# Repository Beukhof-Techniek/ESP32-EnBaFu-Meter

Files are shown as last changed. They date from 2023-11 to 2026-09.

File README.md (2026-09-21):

# ESP32 Engine, Battery & Fuel Meter

## General

This project shows an example design for an ESP32-based adapter with which a number of Engine, Battery and Fuel related properties can be read, interpreted an communicated with a Signal K host. This design has actually been built and is in use on on my own sailboat.

## Features

- Fuel Level as a ratio (percentage) and volume;

- Alternator Voltage;

- Engine Status (stopped/running);

- Engine Running Time (persistent over Power Cycles);

- Battery Voltage for two Batteries;

- WiFi connection to the Boat Network;

- Calibration possibilities;

- Using the ESP32 platform.

## Fuel Level

The value (resistance) of a Fuel or Water Level Sender is indicative for the (remaining) amount of Liquid in the Tank. In this example, a Wema Fuel Level Sender is used which has the VDO type values: 0 Ohm when empty and 190 Ohm when full. Any other type of Linear Sender will do as long as you calibrate it properly.

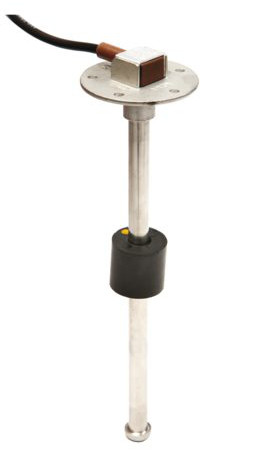
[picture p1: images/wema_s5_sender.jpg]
Wema Fuel and Water Sender


The Sender is connected in series with a 220 Ohm resistor over which the voltage drop is being measured. Due to the inaccuracy of a standard analog input of ESP32 types of processors, an INA219A is being used. A 3.3V zenerdiode keeps a steady voltage over the resistor-sender series connection. The actual value of the Sender determines the voltage drop over the 220 Ohm resistor which in turn is an indication of the Fluid Level in the Tank.

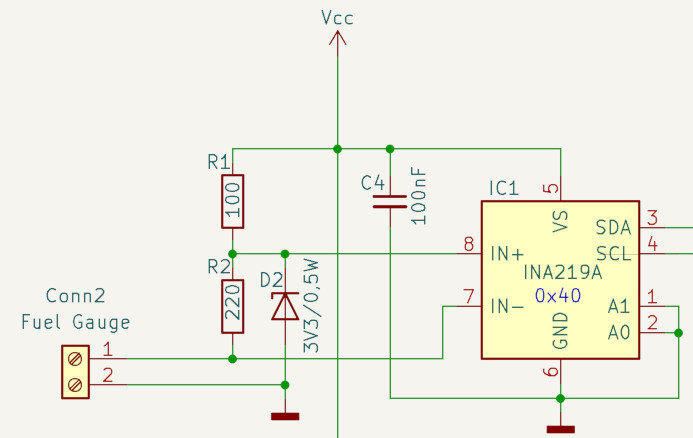
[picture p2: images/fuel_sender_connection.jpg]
Fuel Sender connection


The determined Input Voltage is then calculated into the ratio, a value between 0.0 and 1.0 which can be used to present a percentage (Signal K offers a number of translations), and the volume. The latter is sent to Signal K in m3 but Signal K offers a number of translations for this value as well. Because I found the Wema sender I was using was not linear, there is an additional function with which one can calibrate the resulting values.

The values sent to Signal K are:

- type : the type of Tank;

- capacity : total capacity/volume of the Tank;

- currentLevel : the level of fluid in the Tank as a value 0.0-1.0 (Signal K documentation mentions 0-100% which is incorrect);

- currentVolume : the volume of fluid in the Tank.

## Alternator and Engine values

The Alternator is also connected to an INA219A voltage monitor to obtain an accurate voltage registration. The current sensing capabilities are not being used in this design.

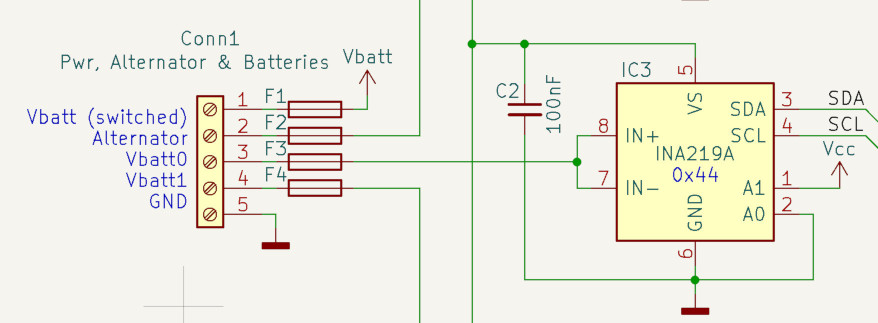
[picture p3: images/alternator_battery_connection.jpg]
Alternator and Battery connection


When the measured voltage is above a certain threshold, the engine is considered as running and time is added to the total runtime and updated in flash memory.

The values sent to Signal K are:

- label : human readable label for the propulsion unit;

- alternatorVoltage : Alternator voltage;

- state : the current state of the Engine;

- runTime : total running time of the Engine (Engine Hours in seconds).

## Battery Voltage

This design provides the possibility to connect and monitor two Batteries. For connection details, see "Alternator and Engine values" above.

The value sent to Signal K is:

- voltage : Voltage measured at or as close as possible to the device.

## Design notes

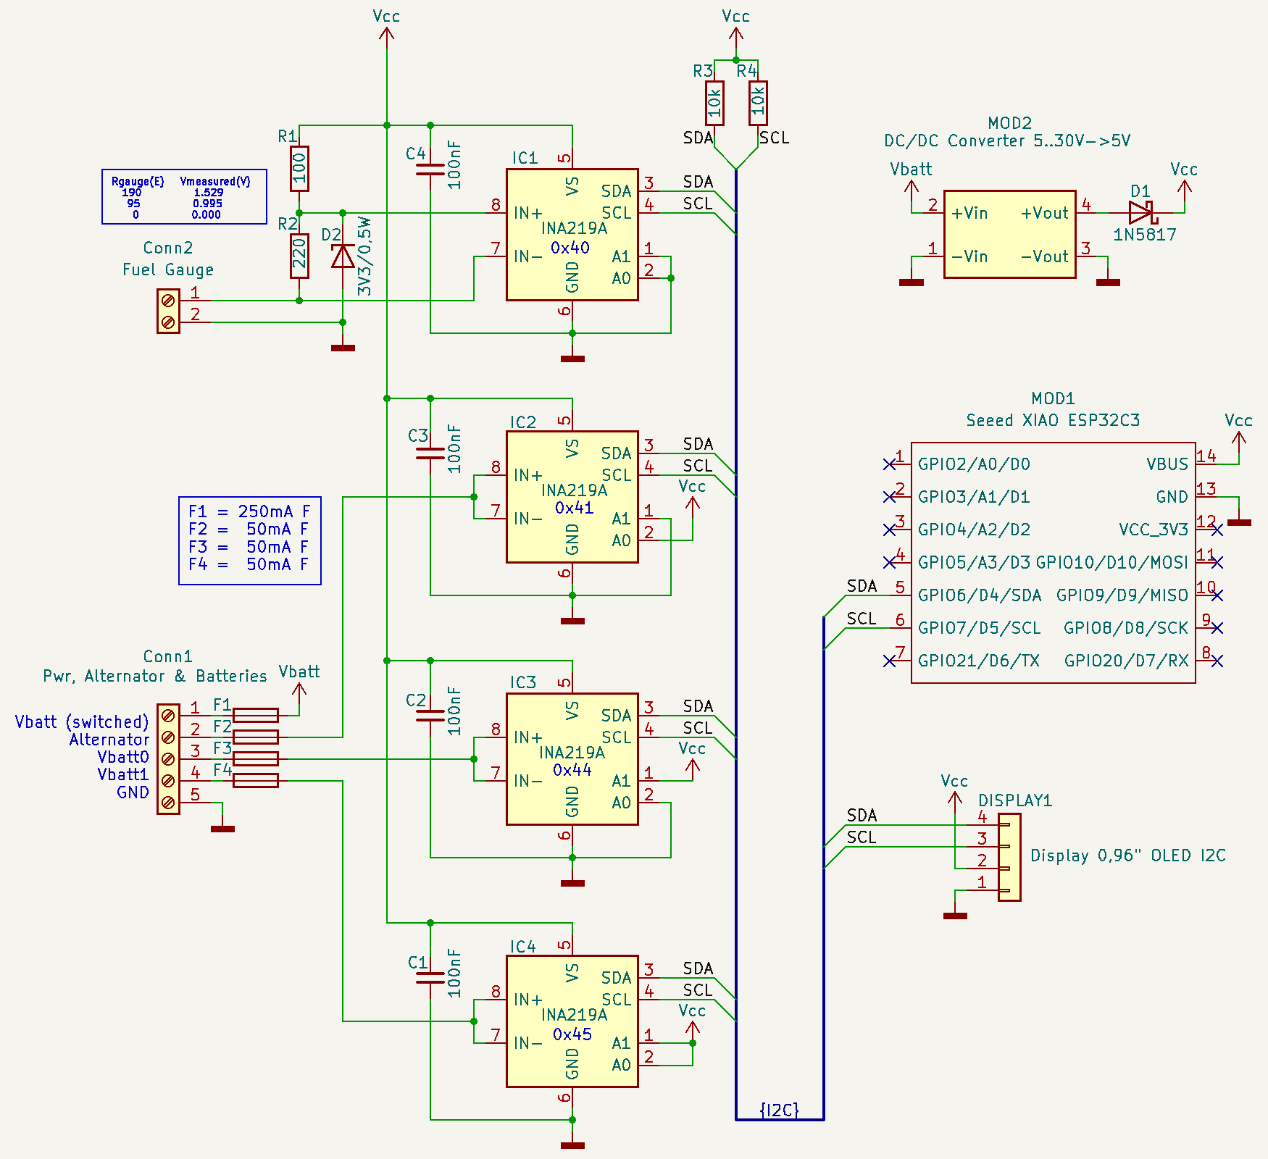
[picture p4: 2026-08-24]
images/enbafu_meter_schematic.png

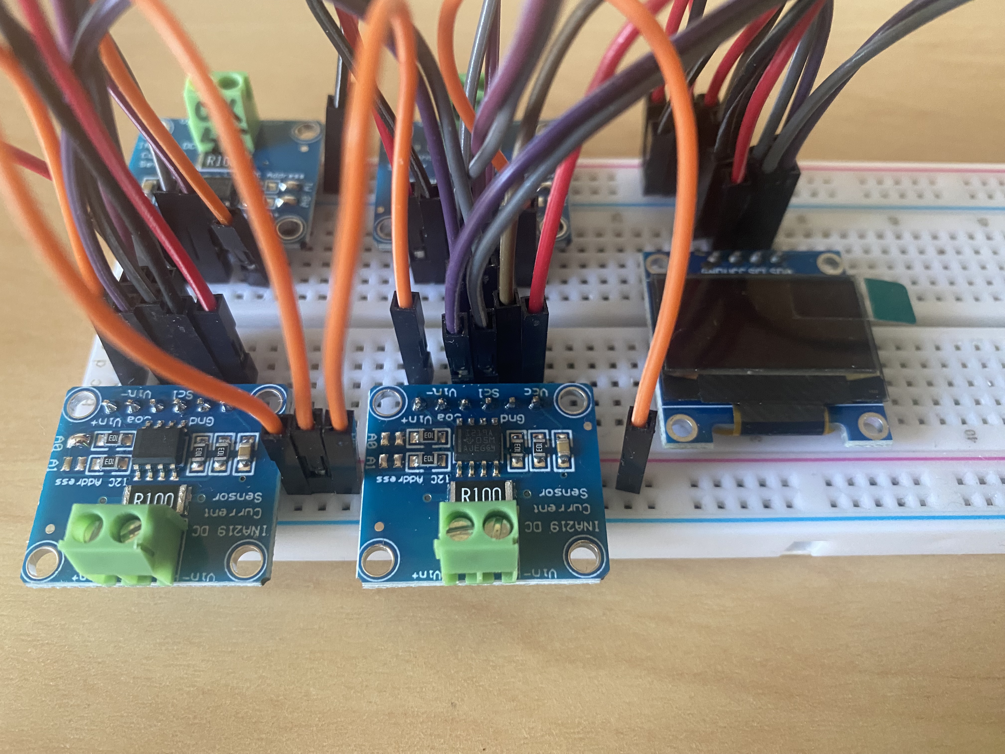
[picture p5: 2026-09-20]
images/breadboard02.jpg

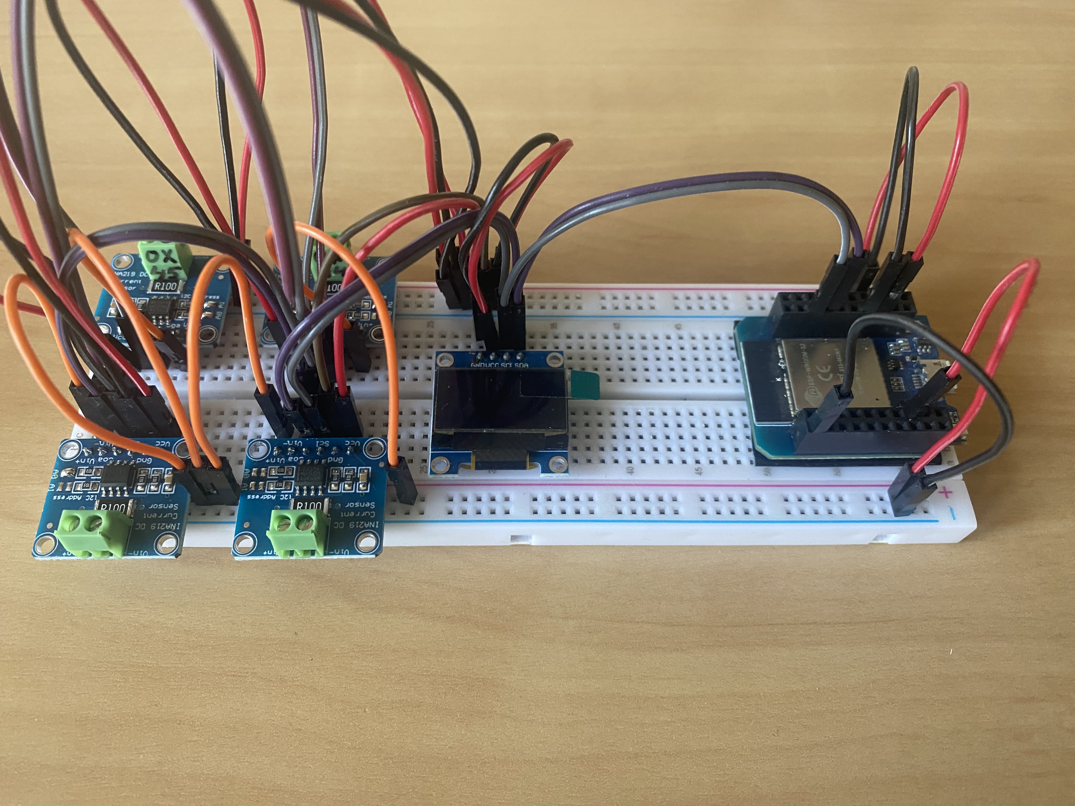
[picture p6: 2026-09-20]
images/breadboard01.jpg

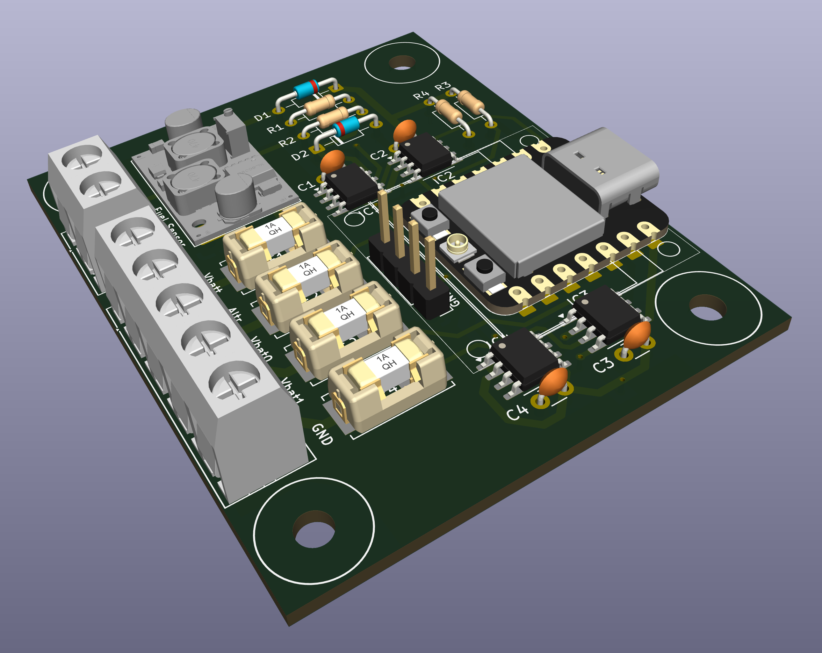
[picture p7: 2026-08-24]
images/enbafu_meter_pcb_3d.png

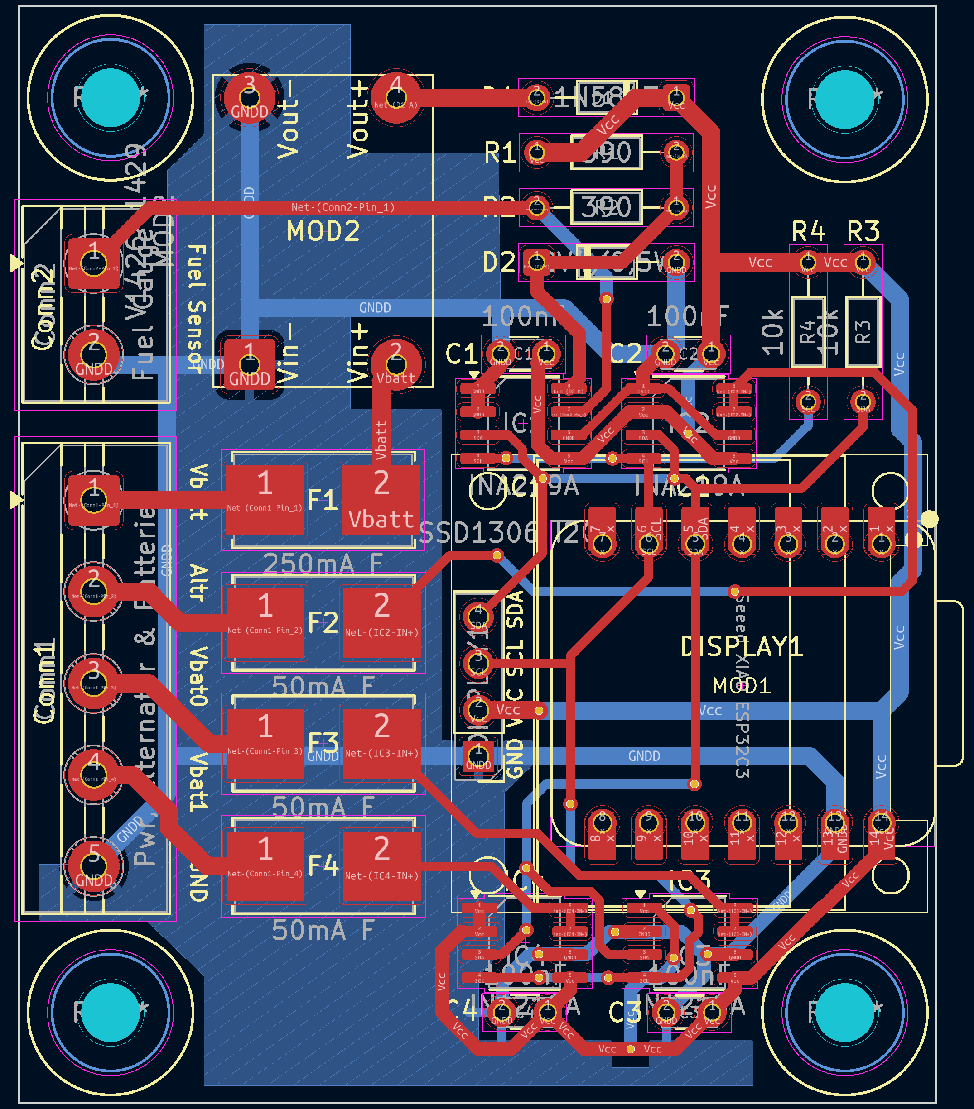
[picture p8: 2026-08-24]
images/enbafu_meter_pcb.png

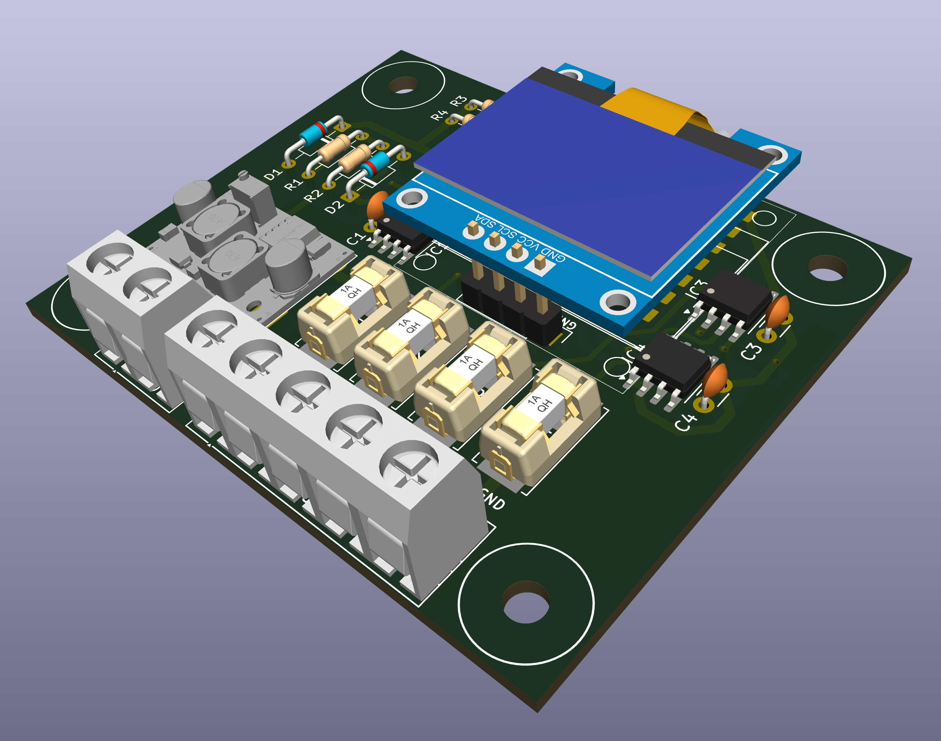
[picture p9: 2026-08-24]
images/enbafu_meter_pcb_3d_oled.png

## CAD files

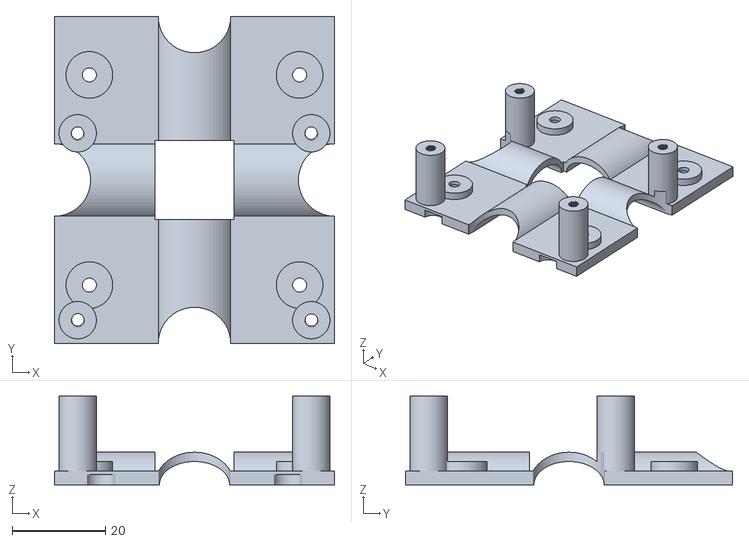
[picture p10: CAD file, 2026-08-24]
documents/EnBaFu Meter Mounting.stl
60.0 x 70.0 x 19.0

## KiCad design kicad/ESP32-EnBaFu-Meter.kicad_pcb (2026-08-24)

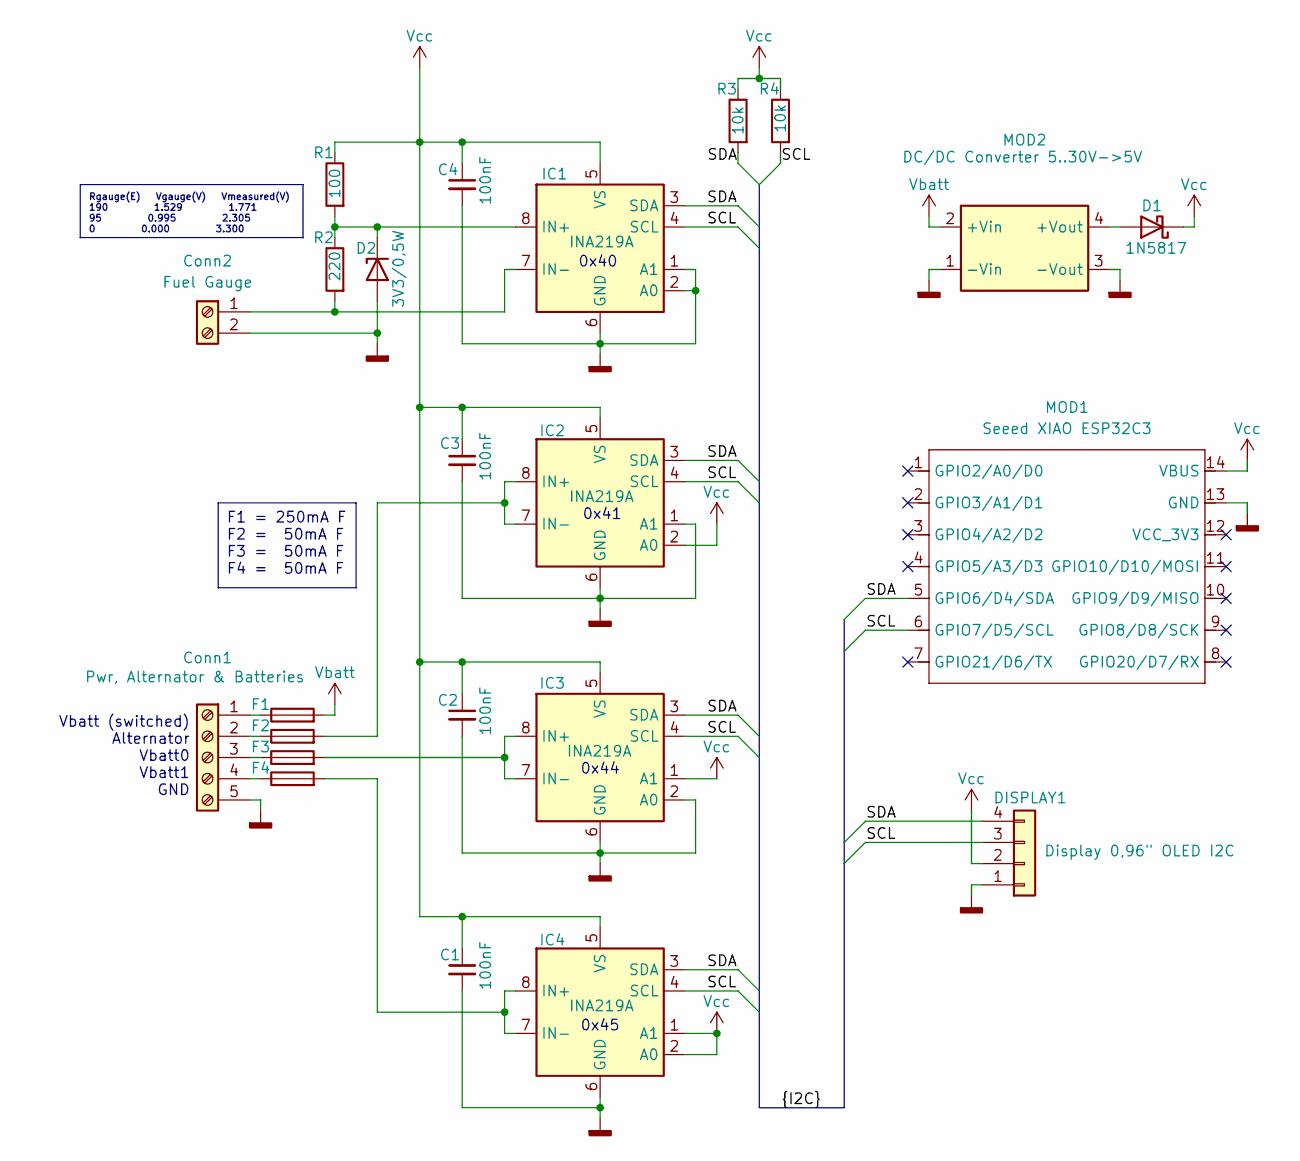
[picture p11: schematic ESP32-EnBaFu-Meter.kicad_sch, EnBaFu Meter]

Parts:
C1, C2, C3, C4: 100nF; C_Disc_D3.0mm_W1.6mm_P2.50mm
Conn1: Pwr, Alternator & Batteries; TerminalBlock_MaiXu_MX126-5.0-05P_1x05_P5.00mm
Conn2: Fuel Gauge; TerminalBlock_MaiXu_MX126-5.0-02P_1x02_P5.00mm
D1: 1N5817; D_DO-34_SOD68_P7.62mm_Horizontal
D2: 3V3/0,5W; D_DO-34_SOD68_P7.62mm_Horizontal
DISPLAY1: Display 0,96" OLED I2C; Display_0.96inch_OLED_IIC
F1: 250mA F; Fuseholder_Littelfuse_Nano2_154x
F2, F3, F4: 50mA F; Fuseholder_Littelfuse_Nano2_154x
IC1, IC2, IC3, IC4: INA219A; SOIC-8_3.9x4.9mm_P1.27mm
MOD1: Seeed XIAO ESP32C3; XIAO-ESP32C3-DIP
MOD2: DC/DC Converter 5..30V->5V; DCDC_Converter_Aliexpress_4pin_17x12mm
R1: 100; R_Axial_DIN0204_L3.6mm_D1.6mm_P7.62mm_Horizontal
R2: 220; R_Axial_DIN0204_L3.6mm_D1.6mm_P7.62mm_Horizontal
R3, R4: 10k; R_Axial_DIN0204_L3.6mm_D1.6mm_P7.62mm_Horizontal

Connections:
/SCL: DISPLAY1.3, IC1.4 (SCL), IC2.4 (SCL), IC3.4 (SCL), IC4.4 (SCL), MOD1.6 (GPIO7/D5/SCL), R4.2
/SDA: DISPLAY1.4, IC1.3 (SDA), IC2.3 (SDA), IC3.3 (SDA), IC4.3 (SDA), MOD1.5 (GPIO6/D4/SDA), R3.2
GNDD: C1.2, C2.2, C3.2, C4.2, Conn1.5, Conn2.2, D2.2 (A), DISPLAY1.1, IC1.1 (A1), IC1.2 (A0), IC1.6 (GND), IC2.1 (A1), IC2.6 (GND), IC3.2 (A0), IC3.6 (GND), IC4.6 (GND), MOD1.13 (GND), MOD2.1 (-Vin), MOD2.3 (-Vout)
unnamed: Conn1.1, F1.1
unnamed: Conn1.2, F2.1
unnamed: Conn1.3, F3.1
unnamed: Conn1.4, F4.1
unnamed: Conn2.1, IC1.7 (IN-), R2.2
unnamed: D1.2 (A), MOD2.4 (+Vout)
unnamed: D2.1 (K), IC1.8 (IN+), R1.2, R2.1
unnamed: F2.2, IC2.7 (IN-), IC2.8 (IN+)
unnamed: F3.2, IC3.7 (IN-), IC3.8 (IN+)
unnamed: F4.2, IC4.7 (IN-), IC4.8 (IN+)
Vbatt: F1.2, MOD2.2 (+Vin)
Vcc: C1.1, C2.1, C3.1, C4.1, D1.1 (K), DISPLAY1.2, IC1.5 (VS), IC2.2 (A0), IC2.5 (VS), IC3.1 (A1), IC3.5 (VS), IC4.1 (A1), IC4.2 (A0), IC4.5 (VS), MOD1.14 (VBUS), R1.1, R3.1, R4.1

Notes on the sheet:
0x44
0x40
0x41
Vbatt (switched) Alternator Vbatt0 Vbatt1 GND
0x45
F1 = 250mA F F2 = 50mA F F3 = 50mA F F4 = 50mA F
Rgauge(E) Vgauge(V) Vmeasured(V) 190 1.529 1.771 95 0.995 2.305 0 0.000 3.300

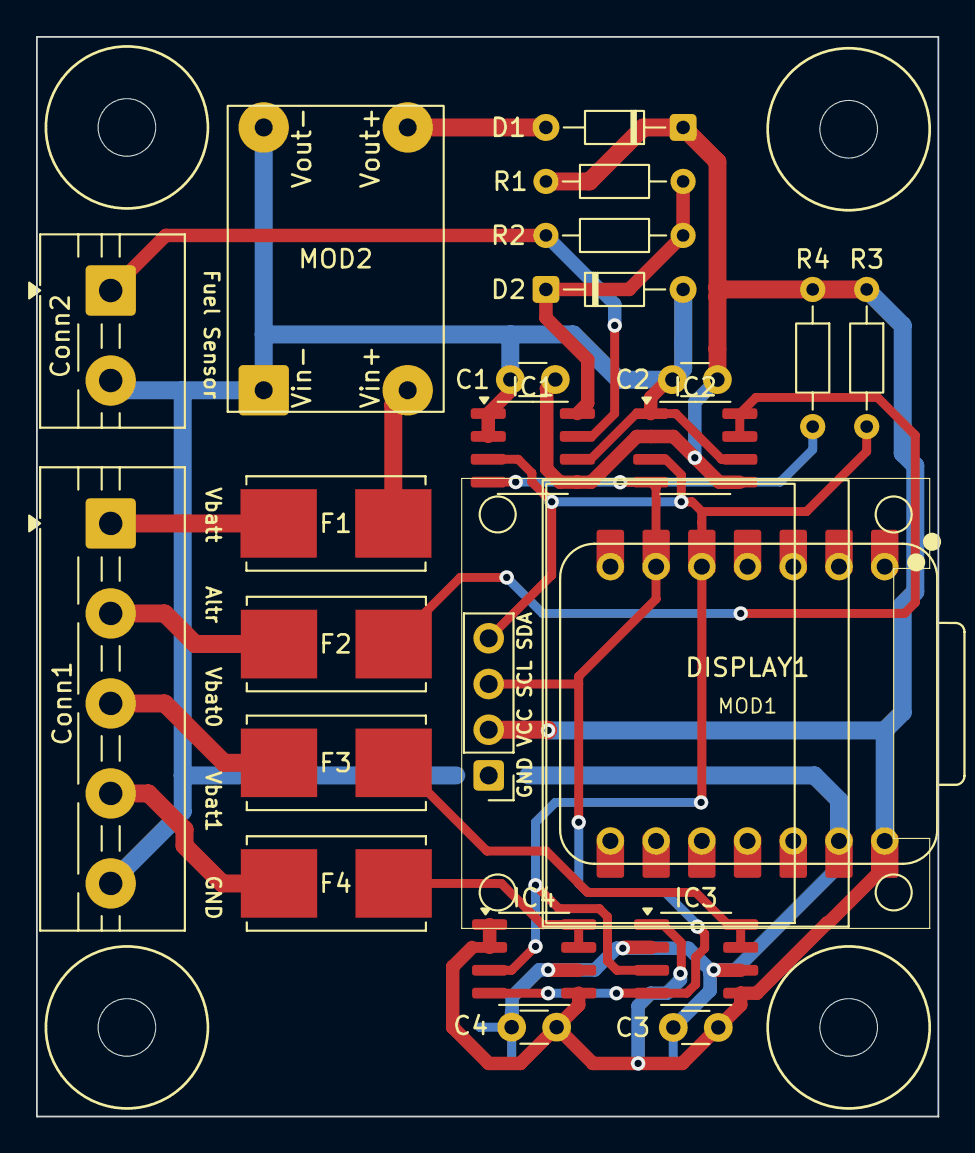
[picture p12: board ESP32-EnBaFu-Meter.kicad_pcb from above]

Board: 2 copper layers, 50.1 x 60.0 mm, 23 parts (0 on the bottom side), 15 nets.

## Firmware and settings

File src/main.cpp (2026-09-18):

// ESP32 Engine, Battery & Fuel Meter for Signal K
//
// This application demonstrates core SensESP concepts in a very
// concise manner. You can build and upload the application as is
// and observe the value changes on the serial port monitor.
//
// You can use this source file as a basis for your own projects.
// Remove the parts that are not relevant to you, and add your own code
// for external hardware libraries.

#include "sensesp_app_builder.h"
#include "sensesp/sensors/analog_input.h"
#include "sensesp/signalk/signalk_output.h"
#include "sensesp/system/lambda_consumer.h"
#include "sensesp/transforms/linear.h"
#include "sensesp/transforms/moving_average.h"
#include <Preferences.h>
#include "includes/EnBaFu_SSD1306.h"
#include <Adafruit_INA219.h>

// *************************************************************************************
// ************************************ PARAMETERS *************************************
// *************************************************************************************

// Replace with your network credentials
const char *wifi_ssid = "your-wifi-devices-ssid";
const char *wifi_password = "your-wifi-devices-password";
const char *hostname = "esp32-enbafu-meter"; // ESP32 Engine, Battery & Fuel Meter (or whatever name you think is valid)

// Replace with your level meter measurements and tank volume
const float tank_voltage_full = 1.660;  // Measured input voltage at full tank (maximum level, use debug info)
const float tank_voltage_empty = 0.000; // Measured input voltage at empty tank (minimum level, use debug info)
const char *tank_type = "diesel";       // Type of tank (diesel, petrol, rum, ...)
const float tank_capacity = 0.060;      // Tank capacity in m3

// Replace with your alternator measurements
// Note: It can be the case that there is a certain voltage on the alternator while the Engine is stopped.
//       This happens for instance when the Alternator is connected to a Victron ArgoFET or similar.
const float alternator_voltage_min = 6.0;      // The minimum voltage from the alternator at which we can safely assume the engine is running (see note above)
unsigned long initial_engine_running_time = 0; // Set this to whatever value you like the runtime counter to start at
                                               // (only needed at the first use or when flash has been cleared). You
                                               // can safely keep it at 0.

// Signal K client config
// Important note: when changing the Signal K server address/connecting to a different Signal K server
// and therefore changing the sk_server_address value below, you need to CLEAR THE FLASH from the ESP
// as well because SensESP stores this value in its config path and prefers that value over whatever
// you feed the builder constructor below. After clearing flash, you might want to re-enter the last known
// engine runTime as the initial_engine_running_time value above to omit the counter starting from 0 again.
const char *sk_server_address = "192.168.20.1";
const uint16_t sk_server_port = 3000;

// *************************************************************************************
// ********************************** END PARAMETERS ***********************************
// *************************************************************************************

#define INA219_FUEL_I2C_ADDRESS (0x40) // Fuel level measurement device
#define INA219_ALTR_I2C_ADDRESS (0x41) // Alternator voltage measurement device
#define INA219_BAT0_I2C_ADDRESS (0x44) // Battery 0 voltage measurement device
#define INA219_BAT1_I2C_ADDRESS (0x45) // Battery 1 voltage measurement device

using namespace sensesp;

Preferences preferences;

// Instantiate the oled display
EnBaFu_SSD1306 oledDisplay(&Wire);

// Instantiate the Vin measurement chips
Adafruit_INA219 ina219_fuel(INA219_FUEL_I2C_ADDRESS); // Fuel level measurement device
Adafruit_INA219 ina219_altr(INA219_ALTR_I2C_ADDRESS); // Alternator voltage measurement device
Adafruit_INA219 ina219_bat0(INA219_BAT0_I2C_ADDRESS); // Battery 0 voltage measurement device
Adafruit_INA219 ina219_bat1(INA219_BAT1_I2C_ADDRESS); // Battery 1 voltage measurement device

String secToHMS(unsigned long seconds){
  if (seconds == 0) {
    return "parameter error";
  } else {
    unsigned long minutes = seconds / 60;
    unsigned long hours = minutes / 60;
    char secondsBuff[3];
    sprintf(secondsBuff, "%02d", seconds%60);
    char minutesBuff[3];
    sprintf(minutesBuff, "%02d", minutes%60);
    return (String)hours + ":" + minutesBuff + ":" + secondsBuff;
  }
}

unsigned long previous_time = 0;
unsigned long engine_running_time = 0;

// Correction function due to non-linearity of the gauge
float gaugeCorrection(float input) {
  // return 1; // For debug purposes such as calibration
  float tank_voltage_relative = (input - tank_voltage_empty) / (tank_voltage_full - tank_voltage_empty);
  if (tank_voltage_relative < 0.131) {
    return 1;
  } else if (tank_voltage_relative < 0.353) {
    return 0.47592;
  } else if (tank_voltage_relative < 0.518) {
    return 0.56386;
  } else if (tank_voltage_relative < 0.63) {
    return 0.63262;
  } else if (tank_voltage_relative < 0.701) {
    return 0.7491;
  } else if (tank_voltage_relative < 0.765) {
    return 0.85041;
  } else if (tank_voltage_relative < 0.851) {
    return 0.94318;
  } else if (tank_voltage_relative < 0.953) {
    return 0.96576;
  } else {
    return 1;
  }
};

/*
 * The setup function performs one-time application initialization.
 */
void setup() {
  SetupLogging();

  /*
   * Set up the OLED display, clears the display and draws the splash screen
   */
  oledDisplay.begin(SSD1306_SWITCHCAPVCC, OLEDDISPLAY_I2C_ADDRESS);
  oledDisplay.clearDisplay(); // Not really necessary because drawSplashScreen() also takes care of this (just in case the splash screen is omitted)
  oledDisplay.setTextSize(1);
  oledDisplay.setTextColor(WHITE);
  oledDisplay.drawSplashScreen();
  delay(2000);  // Give people time to read the splash screen ;)

  /*
   * Set up the INA219 hardware
   */
  ina219_fuel.begin(); // Fuel level measurement device
  ina219_altr.begin(); // Alternator voltage measurement device
  ina219_bat0.begin(); // Battery 0 voltage measurement device
  ina219_bat1.begin(); // Battery 1 voltage measurement device

  /*
   * Construct the global SensESPApp() object
   */
  SensESPAppBuilder builder;
  sensesp_app = builder.set_hostname(hostname)
                      ->set_wifi_client(wifi_ssid, wifi_password)
                      ->set_sk_server(sk_server_address, sk_server_port)
                      ->get_app();

  #ifndef ONLY_SETUP

  // Retrieve the last known engine_running_time value
  if (preferences.begin("propulsion", false)) {
    // When opening the preferences returns a false, the value of engine_running_time will remain 0
    // which will "block" the storage of the parameter further on. Also it will be kept at 0 and shown
    // as such (and the text "parameter error") in the displays so the user will know there is something
    // wrong with the device.
    engine_running_time = preferences.getULong("main_runTime", 1); // Set to default at 1 to get it off the "error" value of 0
  }

  /**
   * Create a series of new Repeat Sensors that obtain data (from the I2C sources) periodically.
   */
  const unsigned int sensor_read_interval = 5000; // Define how often (in milliseconds) new samples are acquired
  auto *tank_voltage = new RepeatSensor<float>(sensor_read_interval, []() { return ina219_fuel.getBusVoltage_V(); });
  auto* alternator_voltage = new RepeatSensor<float>(sensor_read_interval, []() { return ina219_altr.getBusVoltage_V(); });
  auto* battery0_voltage = new RepeatSensor<float>(sensor_read_interval, []() { return ina219_bat0.getBusVoltage_V(); });
  auto* battery1_voltage = new RepeatSensor<float>(sensor_read_interval, []() { return ina219_bat1.getBusVoltage_V(); });
  ESP_LOGD(__FILE__, "tank_voltage, alternator_voltage and batteryx_voltage Instantiated!");

  /**
   * Add observers that print out and display the current value of the obtained data and some calculations every time it changes.
   */
  tank_voltage->attach([tank_voltage]() {
    // Correction of the measured value
    char levelBuffer[5];
    sprintf(levelBuffer, "%d%%", (int)(gaugeCorrection(tank_voltage->get()) * (((tank_voltage->get() - tank_voltage_empty) / (tank_voltage_full - tank_voltage_empty)) * 100)));
    oledDisplay.printAt(35, 42, levelBuffer);
    ESP_LOGI(__FILE__, "\n\nAvailable tank_level values:\ntank_voltage_empty = %f\ntank_voltage_full = %f\nvoltage measured = %f\ncalculated level = %f\n", tank_voltage_empty, tank_voltage_full, tank_voltage->get(), ((tank_voltage->get() - tank_voltage_empty) / (tank_voltage_full - tank_voltage_empty)));
  });
  alternator_voltage->attach([alternator_voltage]() {
    char alternatorBuffer[7];
    sprintf(alternatorBuffer, "%.2fV", alternator_voltage->get());
    oledDisplay.printAt(35, 3, alternatorBuffer);
    oledDisplay.printAt(35, 55, secToHMS(engine_running_time));
    ESP_LOGI(__FILE__, "\n\nAvailable alternator_voltage value:\nvoltage measured = %f\n", alternator_voltage->get());
  });
  battery0_voltage->attach([battery0_voltage]() {
    char battery0Buffer[7];
    sprintf(battery0Buffer, "%.2fV", battery0_voltage->get());
    oledDisplay.printAt(35, 16, battery0Buffer);
    ESP_LOGI(__FILE__, "\n\nAvailable battery0_voltage value:\nvoltage measured = %f\n", battery0_voltage->get());
  });
  battery1_voltage->attach([battery1_voltage]() {
    char battery1Buffer[7];
    sprintf(battery1Buffer, "%.2fV", battery1_voltage->get());
    oledDisplay.printAt(35, 29, battery1Buffer);
    ESP_LOGI(__FILE__, "\n\nAvailable battery1_voltage value:\nvoltage measured = %f\n", battery1_voltage->get());
  });
  ESP_LOGD(__FILE__, "tank_level, alternator_voltage and batteryx_voltage Attached!");

  /**
   * Lambda transformer for registering and storing the Engine Running Time and returning the Engine State
   */
  auto measuredAlternatorVoltageToEngineStateTransformer = new LambdaTransform<float, String>([](float input) -> String {
    unsigned long current_time = millis();
    if (input < alternator_voltage_min) { // Below alternator_voltage_min it is unsure if the engine is running
      previous_time = current_time;
      return "stopped";
    } else if (engine_running_time > 0) {
      if (engine_running_time < initial_engine_running_time) {
        // Set engine_running_time to a certain initial value to start counting from
        engine_running_time = initial_engine_running_time;
      }
      // Calculate runTime in seconds
      engine_running_time += (ulong)(current_time-previous_time)/1000;
      // Store runTime
      preferences.putULong("main_runTime", engine_running_time);
      previous_time = current_time;
      return "running";
    } else { // A value of 0 is an indication that there is something wrong
      previous_time = current_time;
      return "parameter error";
    }
  });

  /**
   * Linear transformers for calibrating output values
   * 
   * gaugeCorrectionTransformer corrects the non-linearity of the fuel gauge (using the gaugeCorrection function)
   * linearTankLevelTransformer takes the tank voltage at minimum level (empty) and maximum level (full) in consideration to create a decent %
   * linearTankVolumeTransformer alse takes the tank capacity into consideration to create a decent volume (m3)
   */
  auto gaugeCorrectionTransformer = new LambdaTransform<float, float>([](float input) -> float {return (input * gaugeCorrection(input));});
  Linear* linearTankLevelTransformer = new Linear((1.0 / (tank_voltage_full - tank_voltage_empty)), ((-1.0 * tank_voltage_empty) / (tank_voltage_full - tank_voltage_empty)));
  Linear *linearTankVolumeTransformer = new Linear((tank_capacity / (tank_voltage_full - tank_voltage_empty)), ((-tank_capacity * tank_voltage_empty) / (tank_voltage_full - tank_voltage_empty)));

  // Connect the analog inputs to Signal K output. This will publish the
  // analog input values to the Signal K server every time it changes.
  //
  // /vessels/<RegExp>/tanks/fuel/<RegExp>/type
  // Description: The type of tank
  // Enum values:
  //   petrol
  //   fresh water
  //   greywater
  //   blackwater
  //   holding
  //   lpg
  //   diesel
  //   liveWell
  //   baitWell
  //   ballast
  //   rum
  tank_voltage->connect_to(new LambdaTransform<float, String>([](float input) -> String { return tank_type; }))
              ->connect_to(new SKOutputString("tanks.fuel.0.type"));
  // /vessels/<RegExp>/tanks/fuel/<RegExp>/capacity
  // Units: m3 (Cubic meter)
  // Description: Total capacity
  tank_voltage->connect_to(new LambdaTransform<float, float>([](float input) -> float { return tank_capacity; }))
              ->connect_to(new SKOutputFloat("tanks.fuel.0.capacity", "", new SKMetadata("m3")));
  // /vessels/<RegExp>/tanks/fuel/<RegExp>/currentLevel
  // Units: ratio (Ratio)
  // Description: Level of fluid in tank 0.0-1.0 (documentation mentions 0-100% which is incorrect)
  tank_voltage->connect_to(new MovingAverage(3))
              ->connect_to(gaugeCorrectionTransformer)
              ->connect_to(linearTankLevelTransformer)
              ->connect_to(new SKOutputFloat("tanks.fuel.0.currentLevel", "", new SKMetadata("ratio")));
  // /vessels/<RegExp>/tanks/fuel/<RegExp>/currentVolume
  // Units: m3 (Cubic meter)
  // Description: Volume of fluid in tank
  tank_voltage->connect_to(new MovingAverage(3))
              ->connect_to(gaugeCorrectionTransformer)
              ->connect_to(linearTankVolumeTransformer)
              ->connect_to(new SKOutputFloat("tanks.fuel.0.currentVolume", "", new SKMetadata("m3")));
  ESP_LOGD(__FILE__, "tank_voltage Connected!");


  // /vessels/<RegExp>/propulsion/<RegExp>/label
  // Description: Human readable label for the propulsion unit
  alternator_voltage->connect_to(new LambdaTransform<float, String>([](float input) -> String { return "Diesel Engine"; }))
                    ->connect_to(new SKOutputString("propulsion.main.label"));
  // /vessels/<RegExp>/propulsion/<RegExp>/alternatorVoltage
  // Units: V (Volt)
  // Description: Alternator voltage
  alternator_voltage->connect_to(new SKOutputFloat("propulsion.main.alternatorVoltage", "", new SKMetadata("V")));
  // /vessels/<RegExp>/propulsion/<RegExp>/state
  // Values (free): "started", "stopped", ...
  // Description: The current state of the engine
  alternator_voltage->connect_to(measuredAlternatorVoltageToEngineStateTransformer)
                    ->connect_to(new SKOutputString("propulsion.main.state"));
  // /vessels/<RegExp>/propulsion/<RegExp>/runTime
  // Units: s (Second)
  // Description: Total running time for engine (Engine Hours in seconds)
  alternator_voltage->connect_to(new LambdaTransform<float, float>([](float input) -> float { return (float)engine_running_time; }))
                    ->connect_to(new SKOutputFloat("propulsion.main.runTime", "", new SKMetadata("s")));
  ESP_LOGD(__FILE__, "alternator_voltage Connected!");


  // /vessels/<RegExp>/electrical/batteries/<RegExp>/voltage
  // Units: V (Volt)
  // Description: Voltage measured at or as close as possible to the device
  battery0_voltage->connect_to(new SKOutputFloat("electrical.batteries.0.voltage", "", new SKMetadata("V")));
  battery1_voltage->connect_to(new SKOutputFloat("electrical.batteries.1.voltage", "", new SKMetadata("V")));


  // Start networking, SK server connections and other SensESP internals
  //debugD("Starting sensesp_app...");
  sensesp_app->start();
  //debugD("sensesp_app Started!");

  oledDisplay.drawIcons();

  #endif // ONLY_SETUP

  ESP_LOGI(__FILE__, "Setup phase complete!");
}

void loop() {
  event_loop()->tick();
}

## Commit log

2023-11-22 Update documentation
    [ESP32-EnBaFu-Meter.kicad_sch]
2026-08-24 Update to I2C
    [Current and Power Calculations.xlsx, ESP32-EnBaFu-Meter.kicad_pcb, ESP32-EnBaFu-Meter.kicad_sch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]
2026-09-18 Added calibration function
